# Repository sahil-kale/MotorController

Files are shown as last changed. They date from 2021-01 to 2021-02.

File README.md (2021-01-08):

# Hornet Hybrid Brushed/Brushless Motor Controller
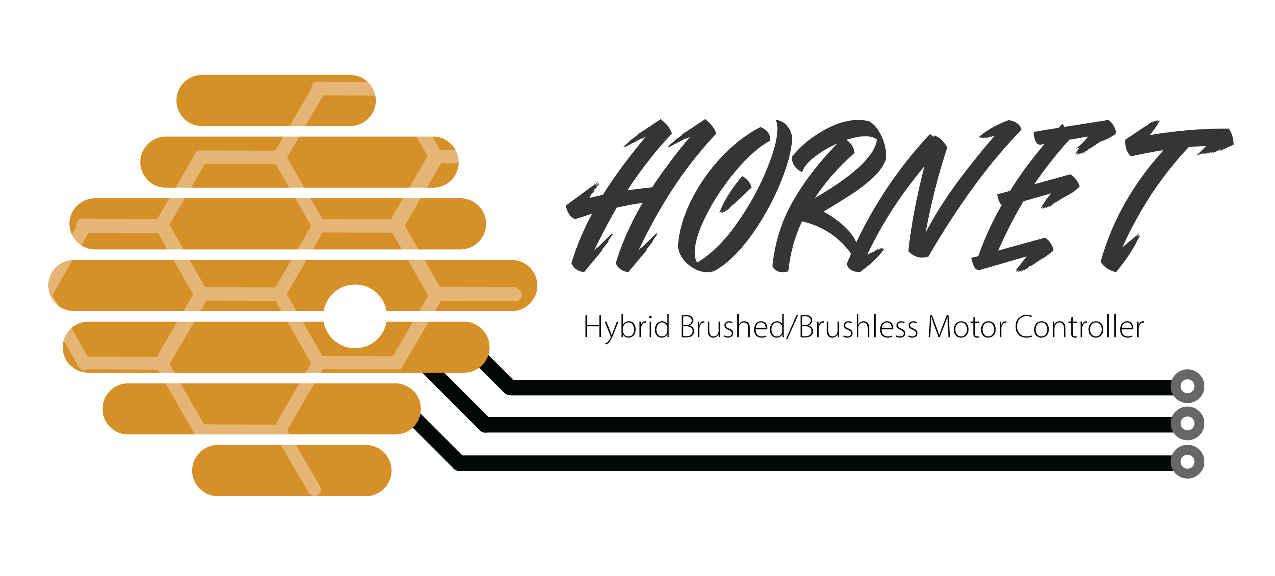
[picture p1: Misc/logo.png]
Logo Photo


## 1.1 General Summary

The HORNET MOTOR CONTROLLER is a 5A/24V hybrid brushed and brushless motor controller designed for robotic applications.

## 1.2 Feature Overview
- Servo-style PWM control interface
- Quadrature Encoder Support
- RGB Status LED
- PIDf Motion Magic
- CAN, UART, and USB data interfaces
- Brake/Coast mode

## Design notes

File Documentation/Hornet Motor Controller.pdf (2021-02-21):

# Hornet Motor Controller

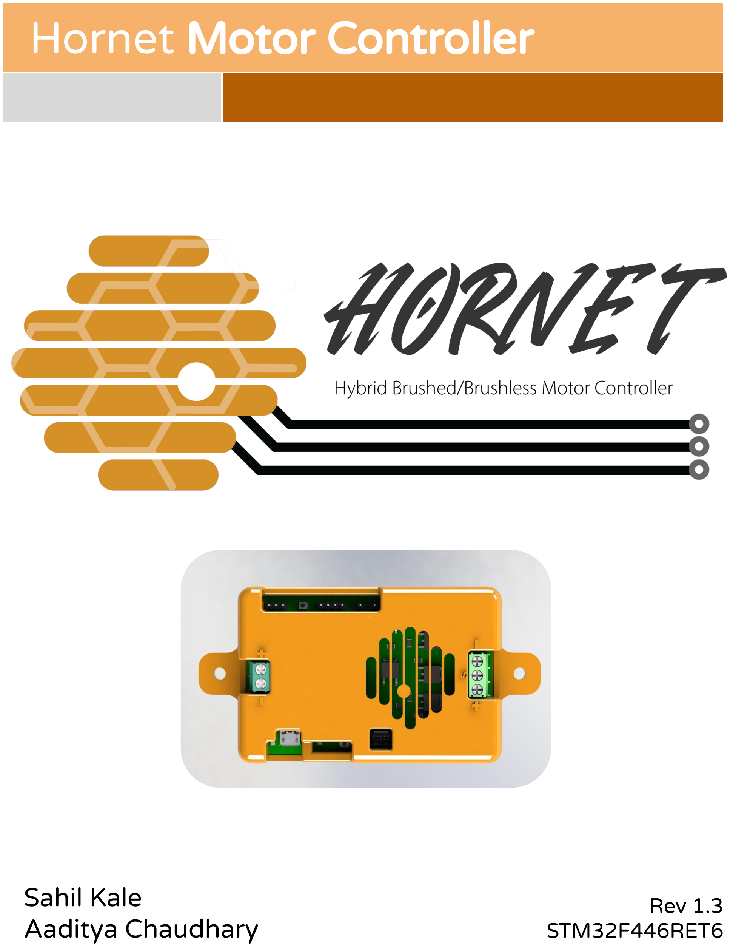
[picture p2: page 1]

## Sahil Kale Aaditya Chaudhary

Rev 1.3
STM32F446RET6

### 1.1 General Summary

The HORNET MOTOR CONTROLLER is a 5A/24V hybrid brushed and brushless motor controller designed for robotic applications based on an ARM Cortex STM32 processor

### 1.2 Feature Overview

- Servo-style PWM control interface
- Quadrature Encoder Support
- RGB Status LED
- PIDF feedback control
- Motion Profiling
- CAN, UART, and USB data interfaces
- Brake/Coast mode

## Section 1 Overview

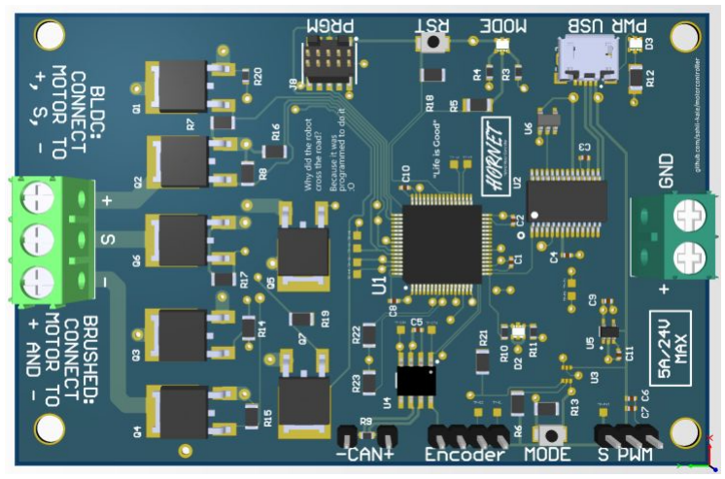
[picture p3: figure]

Figure 1.1 Board View

### 1.3 Pin Mappings

The HORNET MOTOR CONTROLLER features several communication methods . The wiring for these interfaces are located on the left side of the casing. The inputs are broken up into pin headers, in order from top to bottom.

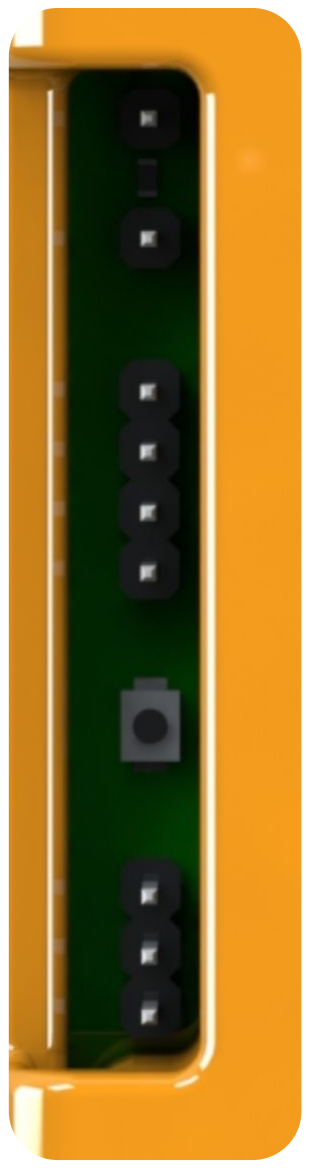
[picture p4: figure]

Controller Area Network (CAN) Wiring
- 1. CAN DIFFERENTIAL LOW
- 2. CAN DIFFERENTIAL HIGH

Quadrature Encoder Pins
- 3. GND
- 4. 5V OUT*
- 5. ENCODER IN 1
- 6. ENCODER IN 2

Servo-Style PWM
- 7. SIGNAL
- 8. 5V I/O*
- 9. GND

*Note: These pins capable of powering an external device at 5V/150 mA within the specified operating limits.

## Section 1 Overview

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
Table 2.1 General Electrical Specifications

Section 2 | Motor Control Specifications
Parameter | Min | Typ | Max | Units
Supply Voltage | 5.5 | - | 24 | V
Max Current | - | - | 5 | A
Output Frequency | - | 2 | - | MHz

Table 2.2 PWM input specifications

Parameter | Min | Typ | Max | Units
Default Full-Forward Pulse | - | 2000 | - | us
Default Neutral Pulse | 1450 | 1500 | 1550 | us
Default Full-Reverse Pulse | - | 1000 | - | us
Input Frequency | 25 | 50 | 100 | Hz
Input Voltage | 3.8 | 5 | 5.5 | V

### 2.2 Brake/Coast Mode

The HORNET MOTOR CONTROLLER features the ability to utilize the connected motor’s counter-electromotive force in order to lock the motor in place. The Brake/Coast mode is toggled in firmware with CAN or UART signals (see Section 3.3.2).

### 2.1 Motor Control Specifications

### 3.1 LED Status Codes

The HORNET MOTOR CONTROLLER features an RGB LED that is used to communicate information about the current state of the controller.

Section 3 | Interfaces
Name | Interval | Interval | Interval | Interval
Proportional Forward
Proportional Back
No Signal, Coast
Neutral Coast
Neutral Brake

Figure 3.1.1 LED Status Codes

### 3.2 CAN/UART Interface

### 3.2.1 CAN Interface Specifics

- CAN ID: 0x254
- Speed: 1Mbit/s

Note that the HORNET MOTOR CONTROLLER has an integrated 120 ohm resistor, allowing it to terminate an existing CAN network

### 3.2.2 UART Interface Specifics

- Baud Rate: 115200

## Section 3 Interfaces

### 3.3 CAN/UART Command Specification

### 3.3.1 Command Format

- Commands are made up of a leading value, to specify the command
- All values following the command specifier are parameters fed into the command

Note that the HORNET MOTOR CONTROLLER can accept a max of 7 parameters and that they must be unsigned 8 bit integers

### 3.3.2 Available Commands

Note that the parameters have been listed

- Set Speed
- Identifier: 0x00
- Parameters:
- Speed, as an unsigned integer from 0-1023, where 0 represents full speed reversed, and 1023 represents full speed forwards
- Set Brushed
- Identifier: 0x01
- Parameters:
- Set Brushed, as an unsigned integer where 0 is false and 1 is true

## Section 3 Interfaces

- Set CAN
- Identifier: 0x02
- Parameters:
- Set whether to use CAN for speed or PWM, as an unsigned 8 bit integer. Send 0 for CAN and 1 for PWM
- Set Coast/Brake
- Identifier: 0x03
- Parameters:
- Unsigned 8 bit integer. Send 0 for coast mode and 1 for brake mode
- Set Acceleration
- Identifier: 0x04
- Parameters:
- Profile number for the trapezoidal profile to modify, starting at 0
- Acceleration, as a double that must be sent as 2 unsigned 8 bit integers
- Set Velocity
- Identifier: 0x05
- Parameters:
- Profile number for the trapezoidal profile to modify, starting at 0
- Max Velocity, as a double that must be sent as 2 unsigned 8 bit integers

## Section 3 Interfaces

- Set P coefficient
- Identifier: 0x06
- Parameters:
- PIDF Profile number, starting at 0
- P coefficient as a double sent as 2 unsigned 8 bit integers
- Set I coefficient
- Identifier: 0x07
- Parameters:
- PIDF Profile number, starting at 0
- I coefficient as a double sent as 2 unsigned 8 bit integers
- Set D coefficient
- Identifier: 0x08
- Parameters:
- PIDF Profile number, starting at 0
- D coefficient as a double sent as 2 unsigned 8 bit integers
- Set F coefficient
- Identifier: 0x09
- Parameters:
- PIDF Profile number, starting at 0
- F coefficient as a double sent as 2 unsigned 8 bit integers

## Section 3 Interfaces

- Start Triangle Motion Profile
- Identifier: 0x10
- Parameters:
- Distance, in encoder ticks,as a 32 bit signed integer sent as 4 unsigned 8 bit integers
- Time, in seconds, as a double sent as 2 unsigned 8 bit integers
- Start Trapezoidal Motion Profile
- Identifier: 0x11
- Parameters:
- Trapezoidal Profile number, starting at 0 [single unsigned 8 bit integer]
- Velocity PIDF Profile to use, starting at 0 [single unsigned 8 bit integer]
- Distance in encoder ticks to travel, as a 32 bit signed integer [4 unsigned 8 bit integers]
- Start PIDF Feedback Control
- Identifier: 0x12
- Parameters:
- Input Type, 0 for encoder position and 1 for encoder velocity [unsigned 8 bit integer]
- Target of the PIDF loop, as a double [ 2 unsigned 8 bit integers]

### 4.1 Triangle Motion Profile Generator

The HORNET MOTOR CONTROLLER can generate triangular motion profiles on the fly, when given both a distance in encoder ticks to travel and the time needed to reach the target. The resulting velocity-time profile does not require a given acceleration because it calculates the acceleration based on the given time and distance. Once the profile is generated, a velocity PIDF config will need be selected to actually follow the profile.

## Section 4 Motion Profiles

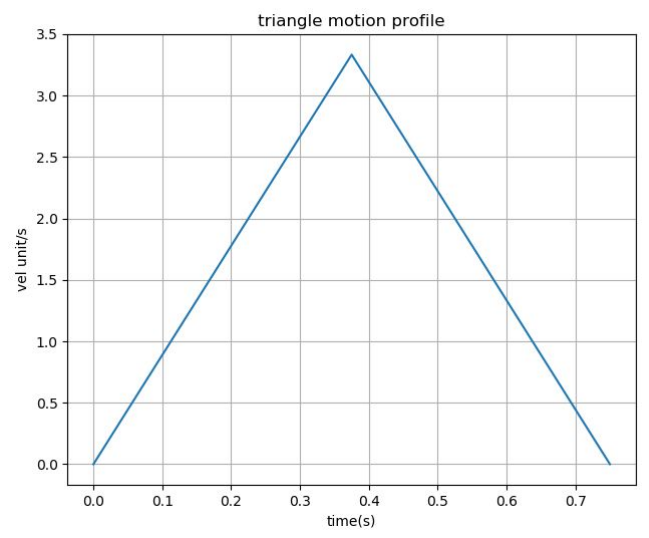
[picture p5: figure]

Figure 4.1.1 Triangle Motion Graph

### 4.2 Trapezoidal Motion Profile Generator

The HORNET MOTOR CONTROLLER can generate trapezoidal motion profiles on the fly, when given a distance in encoder ticks to travel. The controller has 8 available trapezoidal profiles. To use a profile, a max velocity and acceleration must be set for the profile. These values will be used to generate the profile. Once the profile is generated, a PIDF slot will need be selected to follow the profile. If the max velocity is not reached, but half the distance has been traveled, the profile will be a triangular profile rather than a trapezoidal one.

## Section 4 Motion Profiles

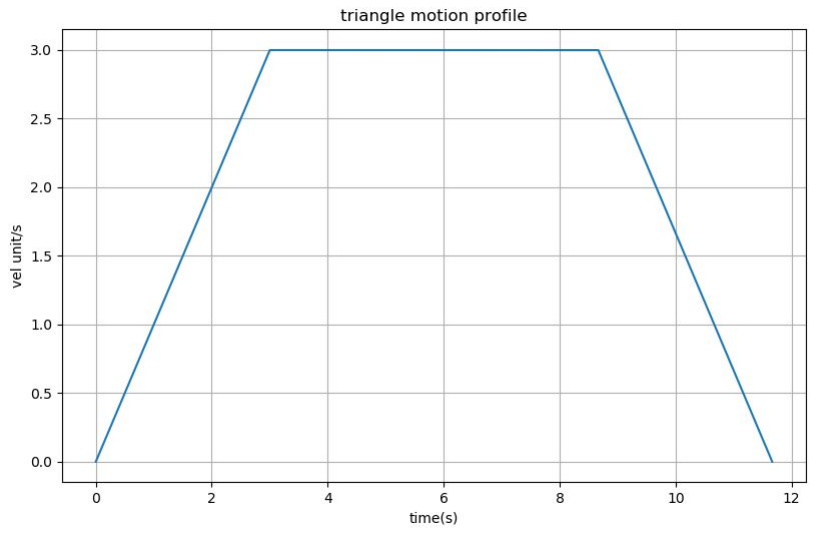
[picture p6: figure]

Figure 4.2.1 Trapezoidal Motion profile graph

## Section 4 Motion Profiles

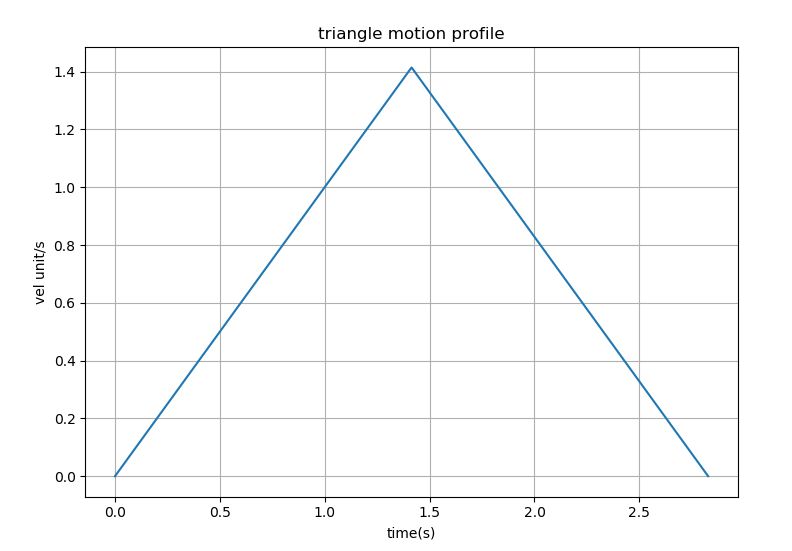
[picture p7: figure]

Figure 4.2.2 Trapezoidal motion profile graph in fallback mode

### 4.3 User Notes

- It is a good idea to test out possible displacement, velocity, and acceleration values with the graphs before using them in practice.
- For most applications, trapezoidal profiles work better and are safer than triangular profiles.
- Trapezoidal profile generator will fallback to a triangle profile if a trapezoidal one can’t be made with the given displacement.

## Appendix A Schematic

### A.1 - Schematic

The schematics for the HORNET MOTOR CONTROLLER are available at the following link:

https://github.com/sahil-kale/MotorController/blob/main/HORNET_MOTOR_CONTROLLER/HORNET_MOTOR_CONTROLLER.pdf (https://github.com/sahil-kale/MotorController/blob/main/HORNET_MOTOR_CONTROLLER/HORNET_MOTOR_CONTROLLER.pdf)

## Appendix B Case Mechanical Drawing

### A.2 - Mechanical Drawing

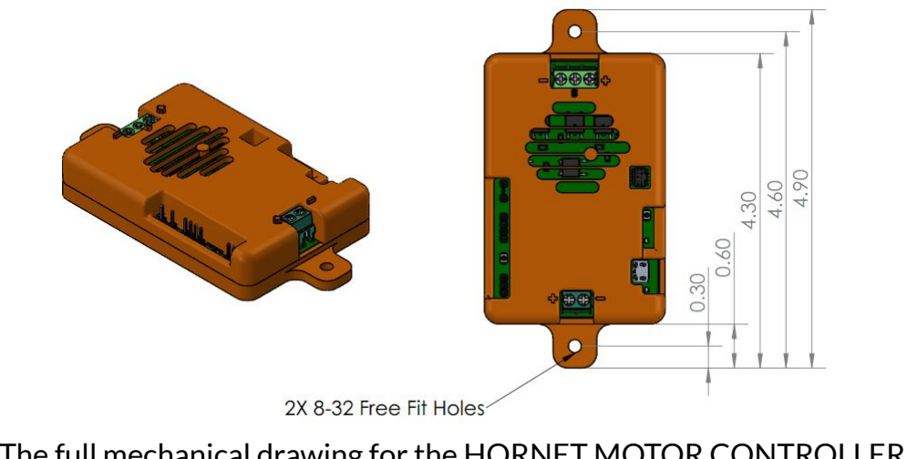
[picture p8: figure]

The full mechanical drawing for the HORNET MOTOR CONTROLLER is available at the following link:

https://github.com/sahil-kale/MotorController/blob/3d-model/3d-model/Hornet_Controller.pdf (https://github.com/sahil-kale/MotorController/blob/3d-model/3d-model/Hornet_Controller.pdf)

## Appendix C Design Decisions

### A.3 Design Decisions

A.3.1 Electrical Design Decisions
- A 4 layer PCB was chosen in order to aid with the relatively high amount of current that the board would be subjected to. Having dedicated ground and power planes ensured that power integrity was not an issue that would be faced by the HORNET MOTOR CONTROLLER.

A.3.2 Processor Decision
- An STM32F446RET6 was chosen as it was a proven microcontroller with 7 unique timer modules (3 are currently used), as well as
UART, CAN, and SPI capability. Although the requirement for SPI was removed partway through development in favour of quadrature encoder support, the capability exists for the HORNET MOTOR CONTROLLER to support SPI encoders.

A.3.3 Firmware Decisions
- As a result of the variety of managers and classes being called by interrupts, singletons were employed in order to ensure that timer modules are utilized in the intended method and that copies of the managers are not inadvertently made. Additionally, compared to static functions, singletons offered the ability to encapsulate our code, increasing its reliability and maintainability.

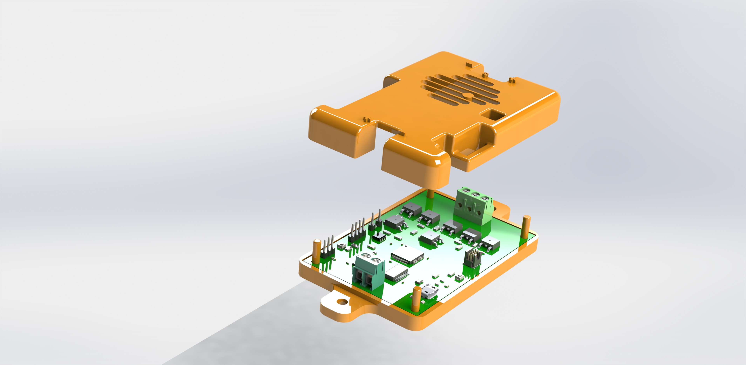
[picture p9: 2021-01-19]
3d-model/OpenCase.JPG

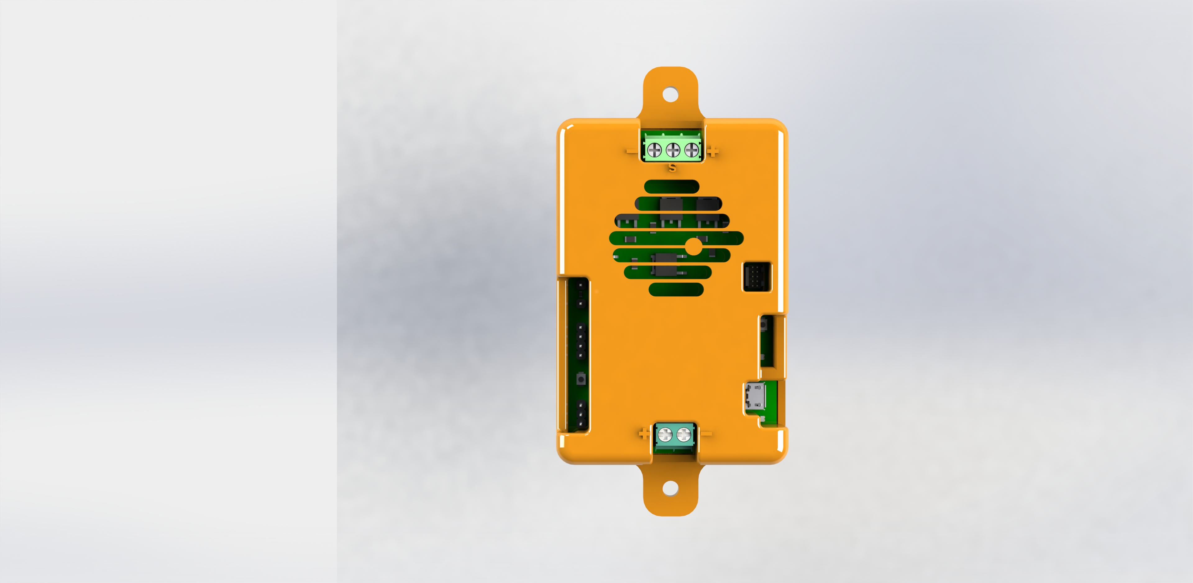
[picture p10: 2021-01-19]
3d-model/TopView.JPG

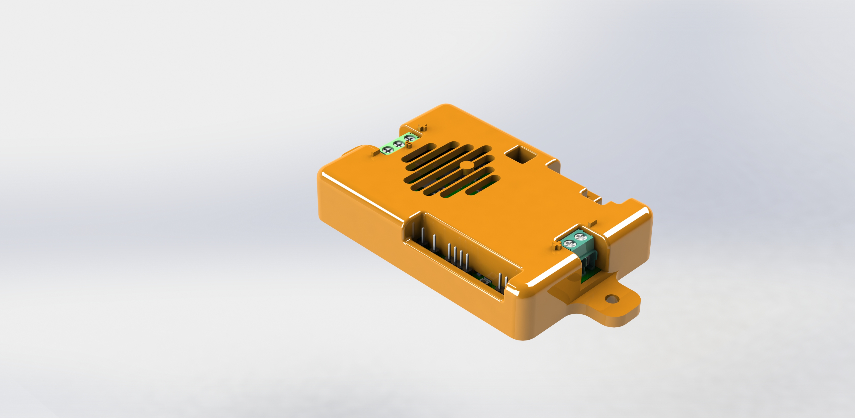
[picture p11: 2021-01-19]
3d-model/AngledView.JPG

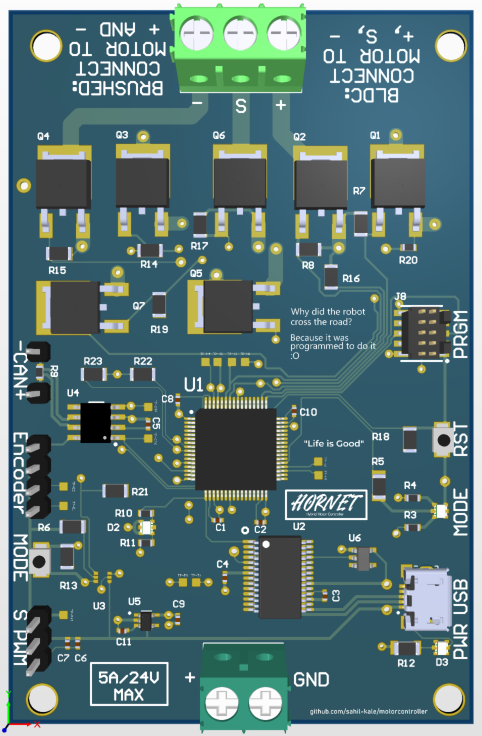
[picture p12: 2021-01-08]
Misc/boardrender.png

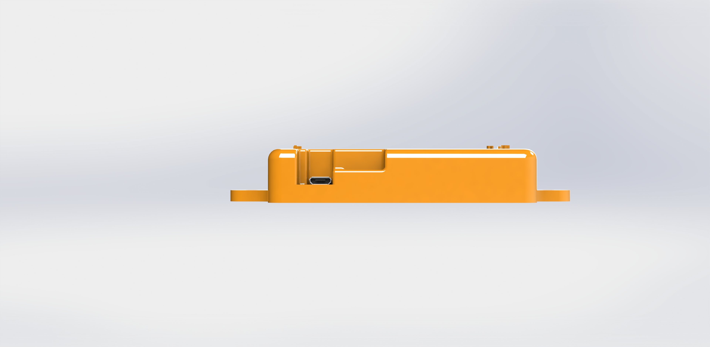
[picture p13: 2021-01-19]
3d-model/LeftView.JPG

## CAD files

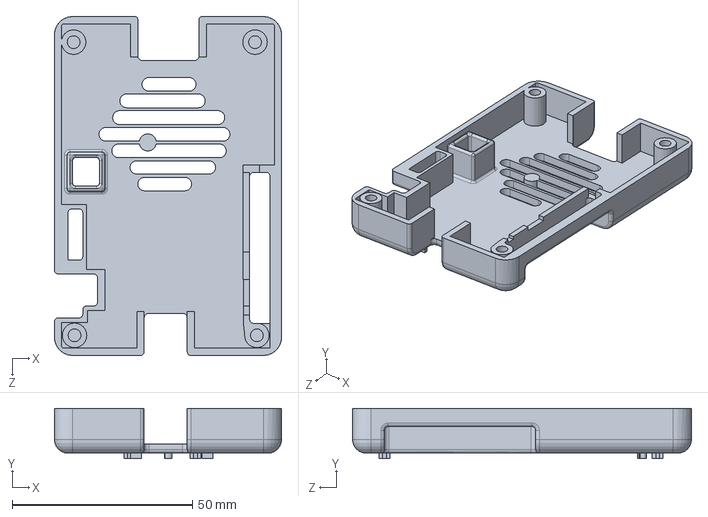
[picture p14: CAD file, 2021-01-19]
3d-model/case_top.SLDPRT
63.0 x 14.0 x 94.0 mm

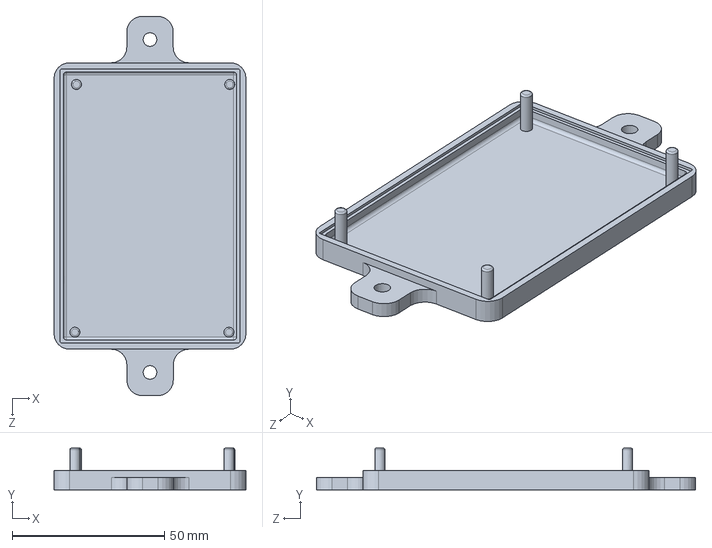
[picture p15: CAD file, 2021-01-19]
3d-model/case_bottom.SLDPRT
63.0 x 13.7 x 124.5 mm

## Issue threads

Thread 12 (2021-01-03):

Mode button toggle & state machine

sahil-kale, 2021-01-03:
There is a mode button on the board. Currently, 2 states are active:
1) Disabled - no output shall be called
2) Enabled

sahil-kale, 2021-01-04:
State machine addon:
3. Motion Magic Mode

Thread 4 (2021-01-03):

PWM input

sahil-kale, 2021-01-03:
PWM input with a servo-style command (50Hz with 5-10% duty cycle) will be used to control the motor.

Closed 2021-01-05.

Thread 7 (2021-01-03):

Encoder Input

sahil-kale, 2021-01-03:
A standard quadrature encoder is supported by this motor controller. GPIO interrupts can be used to make the facilitate of this easier. Once this is done, the inputs can be linked to the outputs via the motion profile functions

Closed 2021-01-08.

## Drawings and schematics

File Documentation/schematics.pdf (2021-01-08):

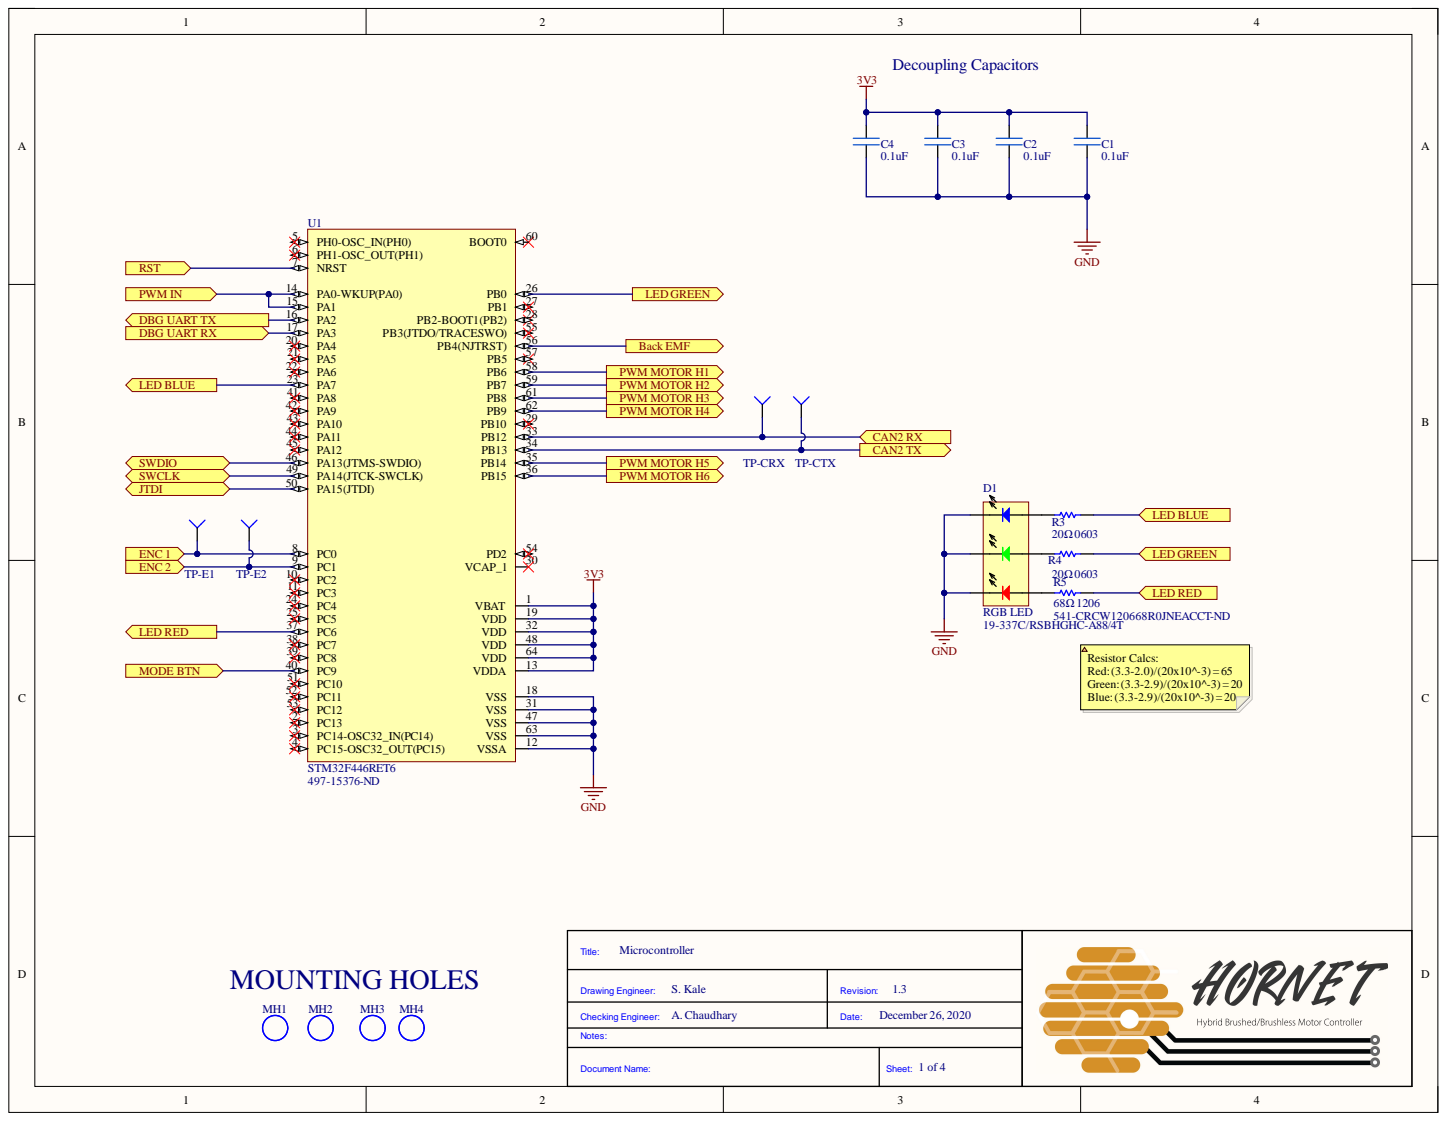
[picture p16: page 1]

TP-CRX TP-CTX

Title: Microcontroller

Drawing Engineer: S. Kale | Revision: 1.3

Checking Engineer: A. Chaudhary | Date: December 26, 2020

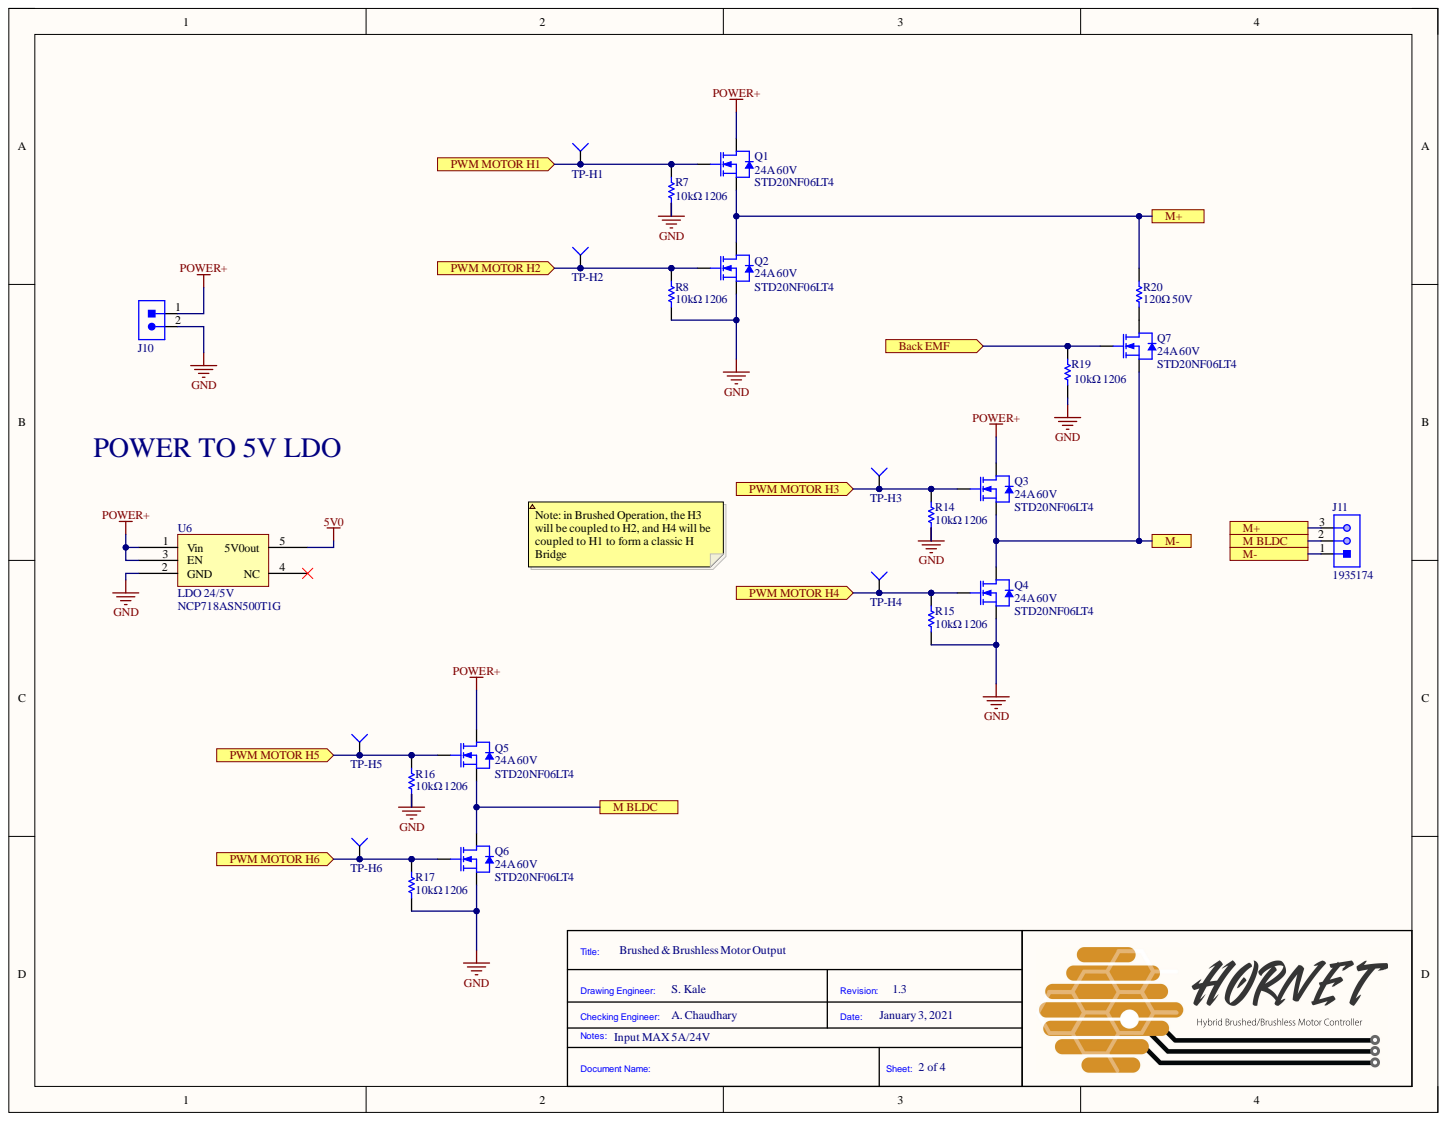
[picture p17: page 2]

Note: in Brushed Operation, the H3
will be coupled to H2, and H4 will be
coupled to H1 to form a classic H
Bridge

Title: Brushed & BrushlessMotor Output

Drawing Engineer: S. Kale | Revision: 1.3

Checking Engineer: A. Chaudhary | Date: January 3, 2021

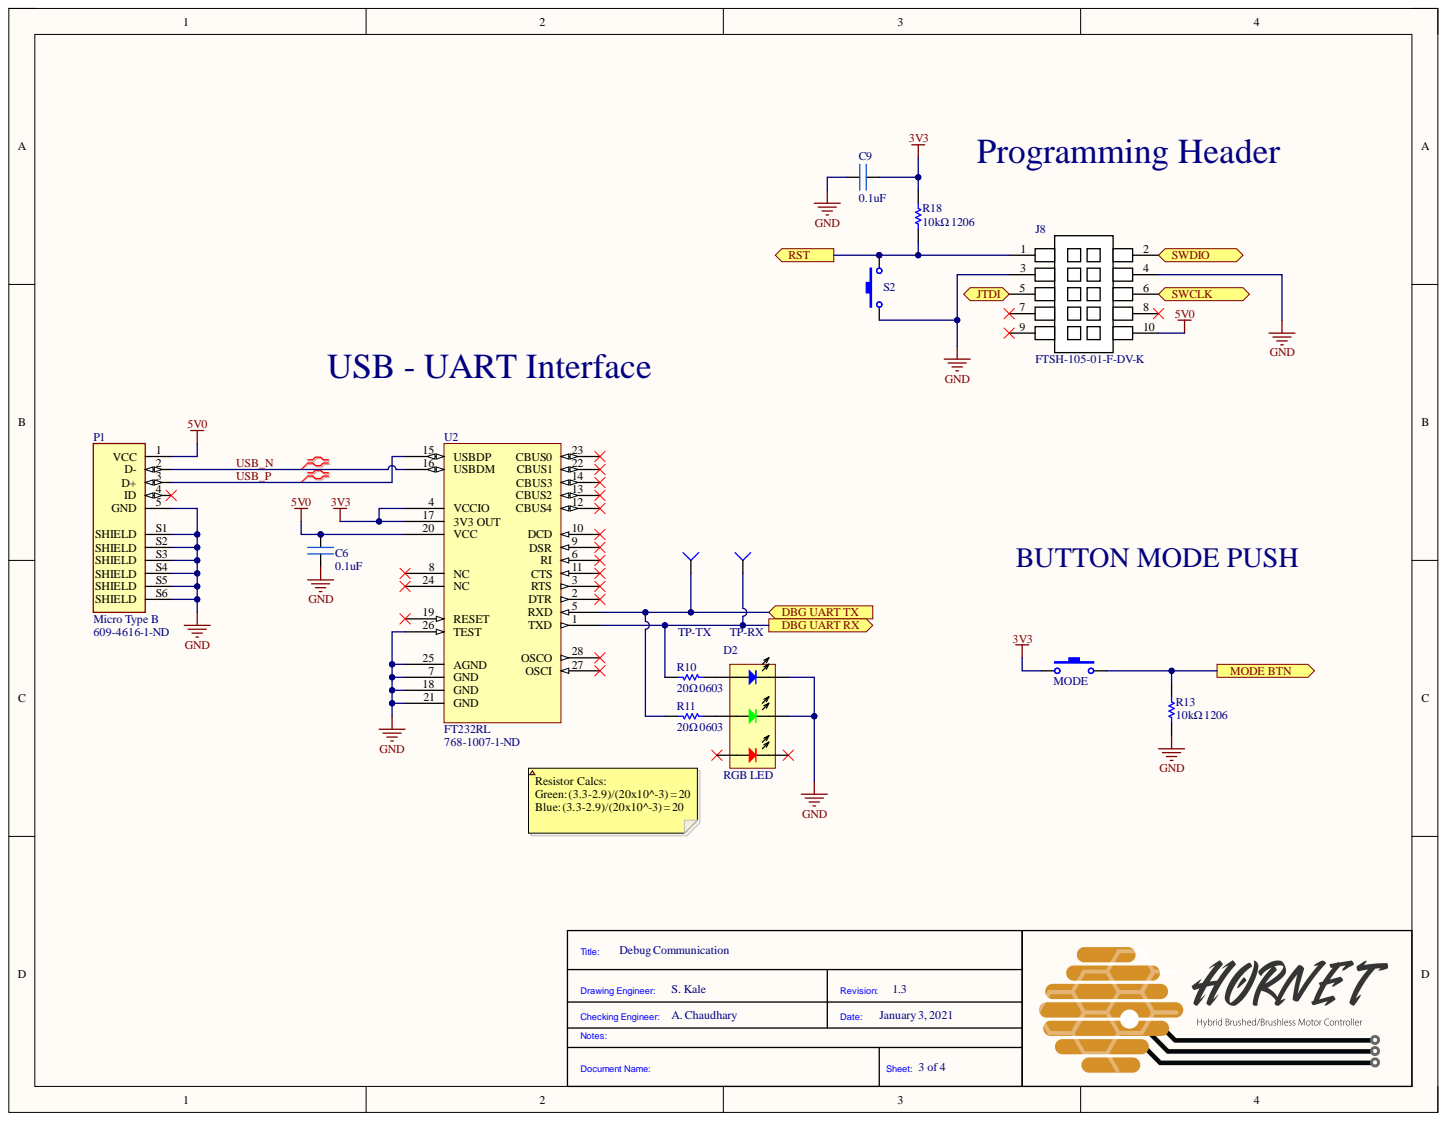
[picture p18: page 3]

AGND 25
GND 7
GND 18
GND 21

Title: DebugCommunication

Drawing Engineer: S. Kale | Revision: 1.3

Checking Engineer: A. Chaudhary | Date: January 3, 2021

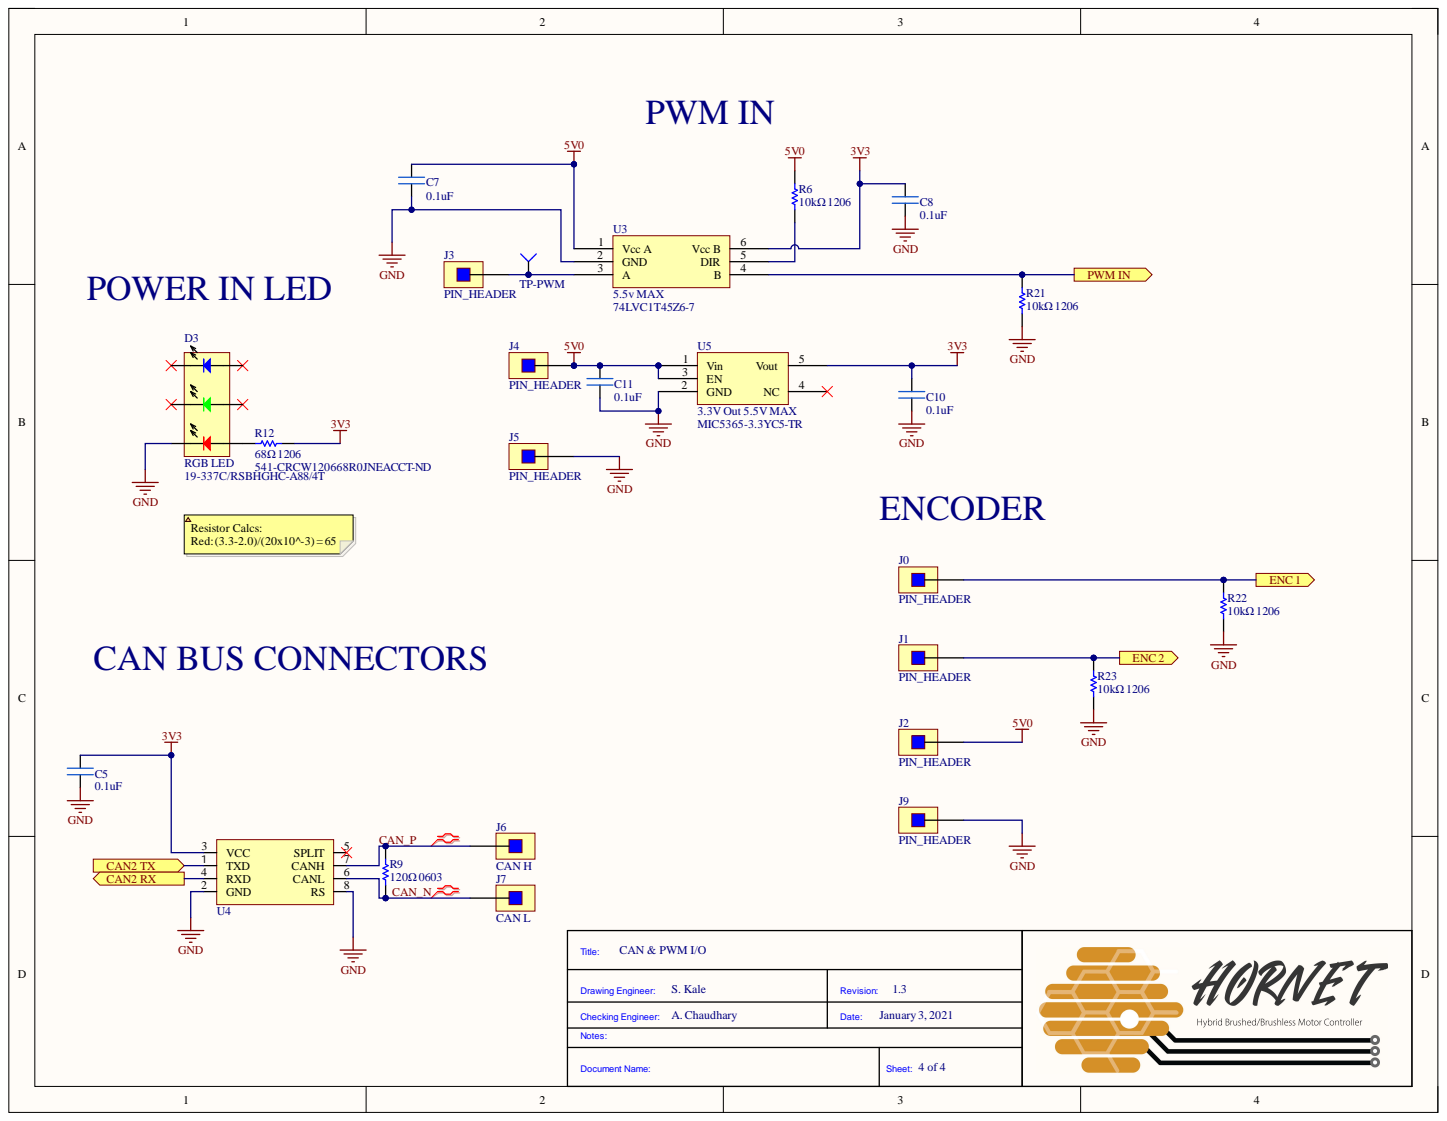
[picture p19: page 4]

Title: CAN & PWM I/O

Drawing Engineer: S. Kale | Revision: 1.3

Checking Engineer: A. Chaudhary | Date: January 3, 2021

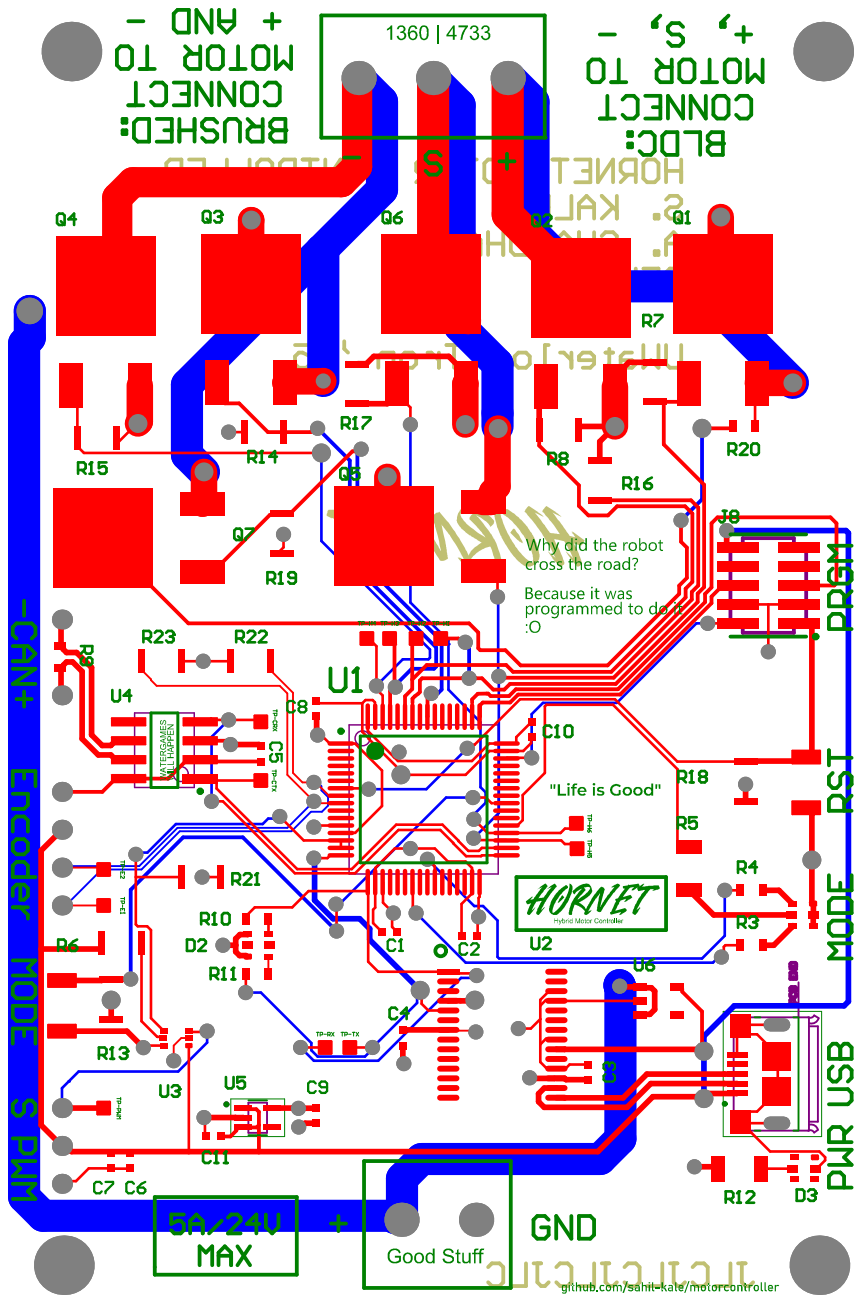
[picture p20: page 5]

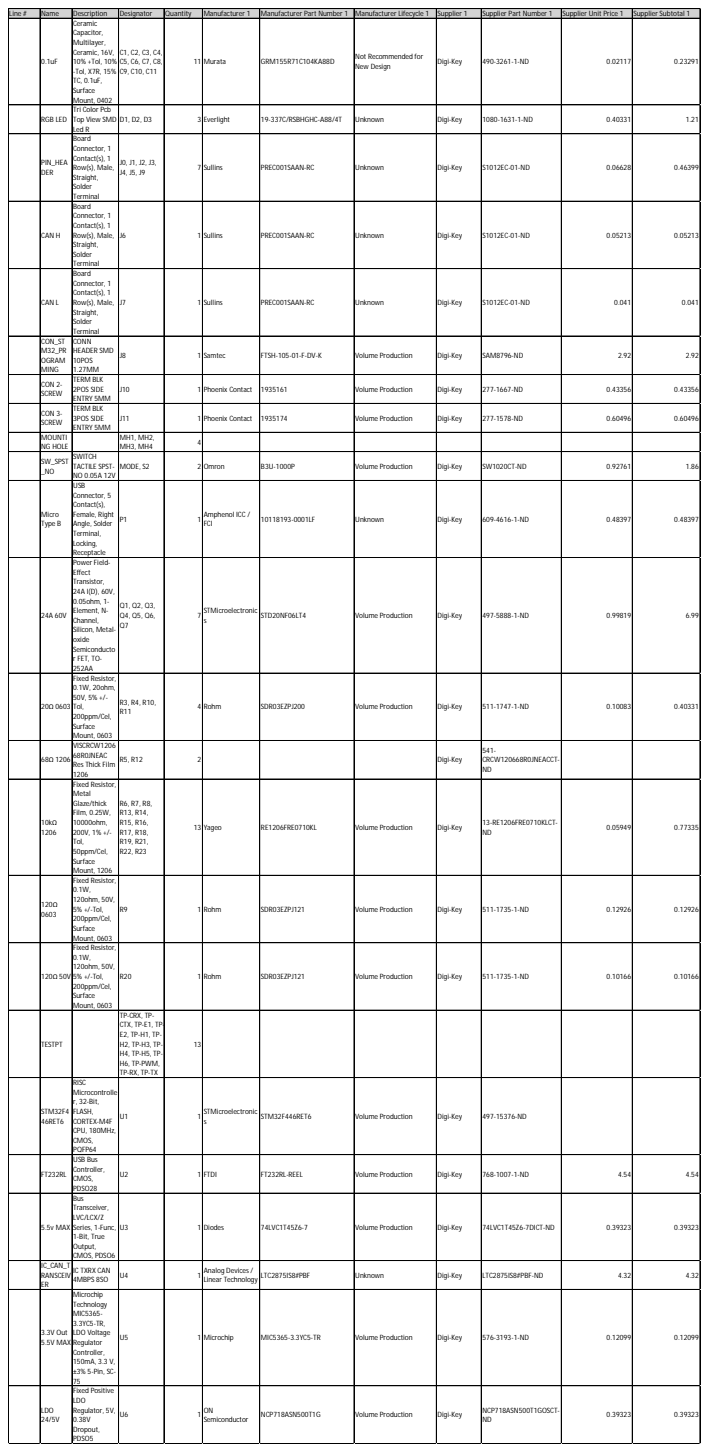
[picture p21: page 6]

0.1uF | Ceramic Capacitor, Multilayer, Ceramic, 16V, 10% +Tol, 10% -Tol, X7R, 15% TC, 0.1uF, Surface Mount, 0402 | C1, C2, C3, C4, C5, C6, C7, C8, C9, C10, C11 | 11 | Murata | GRM155R71C104KA88D | Not Recommended for New Design | Digi-Key | 490-3261-1-ND | 0.02117 | 0.23291

RGB LED | Tri Color Pcb Top View SMD Led R | D1, D2, D3 | 3 Everlight | | 19-337C/RSBHGHC-A88/4T | Unknown | Digi-Key | 1080-1631-1-ND | 0.40331 | 1.21

PIN_HEA DER | Board Connector, 1 Contact(s), 1 Row(s), Male, Straight, Solder Terminal | J0, J1, J2, J3, J4, J5, J9 | 7 | Sullins | PREC001SAAN-RC | Unknown | Digi-Key | S1012EC-01-ND | 0.06628 | 0.46399

CAN H | Board Connector, 1 Contact(s), 1 Row(s), Male, Straight, Solder Terminal | J6 | 1 | Sullins | PREC001SAAN-RC | Unknown | Digi-Key | S1012EC-01-ND | 0.05213 | 0.05213

CAN L | Board Connector, 1 Contact(s), 1 Row(s), Male, Straight, Solder Terminal | J7 | 1 | Sullins | PREC001SAAN-RC | Unknown | Digi-Key | S1012EC-01-ND | 0.041 | 0.041

CON_ST M32_PR OGRAM MING | CONN HEADER SMD 10POS 1.27MM | J8 | 1 | Samtec | FTSH-105-01-F-DV-K | Volume Production | Digi-Key | SAM8796-ND | 2.92 | 2.92

CON 2-SCREW | TERM BLK 2POS SIDE ENTRY 5MM | J10 | 1 | Phoenix Contact | 1935161 | Volume Production | Digi-Key | 277-1667-ND | 0.43356 | 0.43356

CON 3-SCREW | TERM BLK 3POS SIDE ENTRY 5MM | J11 | 1 | Phoenix Contact | 1935174 | Volume Production | Digi-Key | 277-1578-ND | 0.60496 | 0.60496

MOUNTI NG HOLE | | MH1, MH2, MH3, MH4 | 4

SW_SPST _NO | SWITCH TACTILE SPST-NO 0.05A 12V | MODE, S2 | 2 Omron | | B3U-1000P | Volume Production | Digi-Key | SW1020CT-ND | 0.92761 | 1.86

Micro Type B | USB Connector, 5 Contact(s), Female, Right Angle, Solder Terminal, Locking, Receptacle | P1 | 1 | Amphenol ICC / FCI | 10118193-0001LF | Unknown | Digi-Key | 609-4616-1-ND | 0.48397 | 0.48397

24A 60V | Power Field-Effect Transistor, 24A I(D), 60V, 0.05ohm, 1-Element, N-Channel, Silicon, Metal-oxide Semiconducto r FET, TO-252AA | Q1, Q2, Q3, Q4, Q5, Q6, Q7 | 7 | STMicroelectronic s | STD20NF06LT4 | Volume Production | Digi-Key | 497-5888-1-ND | 0.99819 | 6.99

20Ω 0603 | Fixed Resistor, 0.1W, 20ohm, 50V, 5% +/-Tol, 200ppm/Cel, Surface Mount, 0603 | R3, R4, R10, R11 | 4 Rohm | | SDR03EZPJ200 | Volume Production | Digi-Key | 511-1747-1-ND | 0.10083 | 0.40331

68Ω 1206 | VISCRCW1206 68R0JNEAC Res Thick Film 1206 | R5, R12 | 2 | | | | Digi-Key | 541-CRCW120668R0JNEACCT-ND

10kΩ 1206 | Fixed Resistor, Metal Glaze/thick Film, 0.25W, 10000ohm, 200V, 1% +/-Tol, 50ppm/Cel, Surface Mount, 1206 | R6, R7, R8, R13, R14, R15, R16, R17, R18, R19, R21, R22, R23 | 13 Yageo | | RE1206FRE0710KL | Volume Production | Digi-Key | 13-RE1206FRE0710KLCT-ND | 0.05949 | 0.77335

120Ω 0603 | Fixed Resistor, 0.1W, 120ohm, 50V, 5% +/-Tol, 200ppm/Cel, Surface Mount, 0603 | R9 | 1 | Rohm | SDR03EZPJ121 | Volume Production | Digi-Key | 511-1735-1-ND | 0.12926 | 0.12926

120Ω 50V | Fixed Resistor, 0.1W, 120ohm, 50V, 5% +/-Tol, 200ppm/Cel, Surface Mount, 0603 | R20 | 1 | Rohm | SDR03EZPJ121 | Volume Production | Digi-Key | 511-1735-1-ND | 0.10166 | 0.10166

TESTPT | | TP-CRX, TP-CTX, TP-E1, TP-E2, TP-H1, TP-H2, TP-H3, TP-H4, TP-H5, TP-H6, TP-PWM, TP-RX, TP-TX | 13

STM32F4 46RET6 | RISC Microcontrolle r, 32-Bit, FLASH, CORTEX-M4F CPU, 180MHz, CMOS, PQFP64 | U1 | 1 | STMicroelectronic s | STM32F446RET6 | Volume Production | Digi-Key | 497-15376-ND

FT232RL | USB Bus Controller, CMOS, PDSO28 | U2 | 1 | FTDI | FT232RL-REEL | Volume Production | Digi-Key | 768-1007-1-ND | 4.54 | 4.54
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

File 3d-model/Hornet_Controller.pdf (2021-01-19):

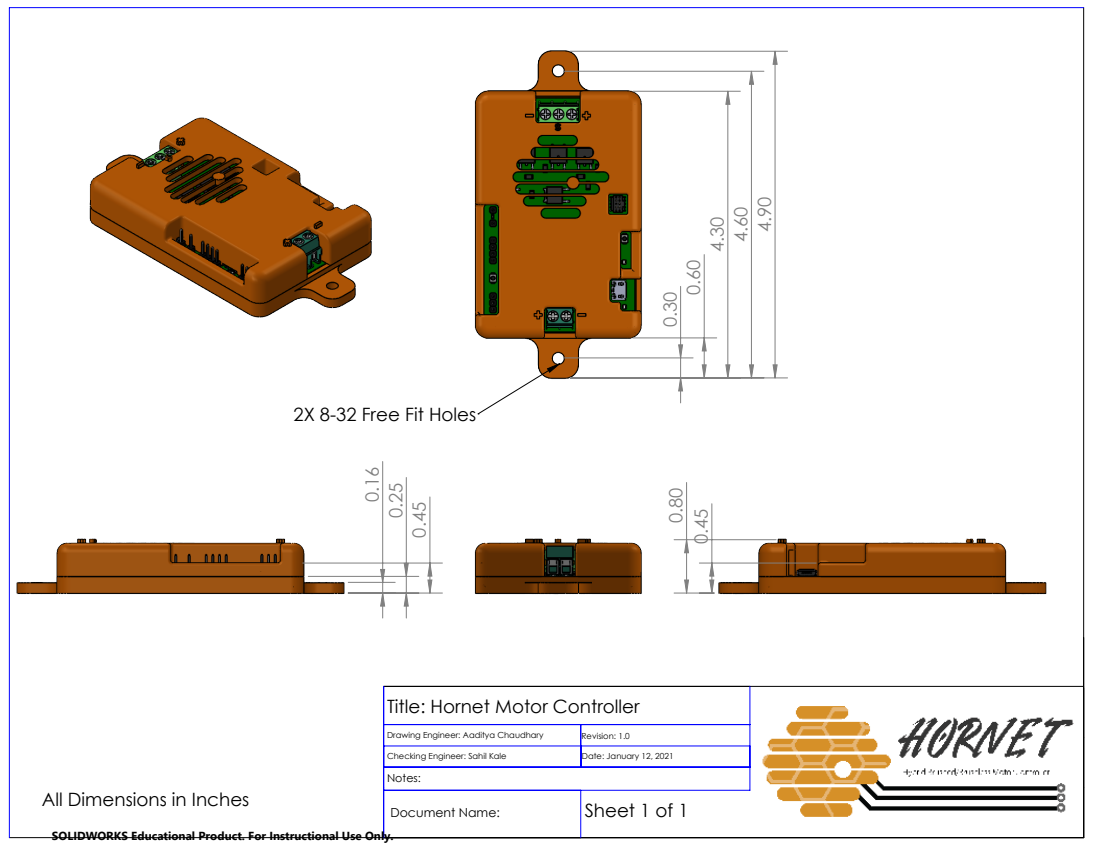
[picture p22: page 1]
Document Name:; Sheet 1 of 1

2X 8-32 Free Fit Holes 0.45 0.16 0.25

Title: Hornet Motor Controller

Drawing Engineer: Aaditya Chaudhary | Revision: 1.0

Checking Engineer: Sahil Kale | Date: January 12, 2021

All Dimensions in Inches

SOLIDWORKS Educational Product. For Instructional Use Only.

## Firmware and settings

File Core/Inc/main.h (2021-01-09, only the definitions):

#define ENC_1_Pin GPIO_PIN_0
#define ENC_1_GPIO_Port GPIOC
#define ENC_1_EXTI_IRQn EXTI0_IRQn
#define ENC_2_Pin GPIO_PIN_1
#define ENC_2_GPIO_Port GPIOC
#define ENC_2_EXTI_IRQn EXTI1_IRQn
#define LED_RED_Pin GPIO_PIN_6
#define LED_RED_GPIO_Port GPIOA
#define LED_GREEN_Pin GPIO_PIN_0
#define LED_GREEN_GPIO_Port GPIOB
#define MOTOR_H5_Pin GPIO_PIN_14
#define MOTOR_H5_GPIO_Port GPIOB
#define MOTOR_H6_Pin GPIO_PIN_15
#define MOTOR_H6_GPIO_Port GPIOB
#define LED_BLUE_Pin GPIO_PIN_7
#define LED_BLUE_GPIO_Port GPIOC
#define MODE_BTN_Pin GPIO_PIN_9
#define MODE_BTN_GPIO_Port GPIOC
#define BackEMF_Pin GPIO_PIN_4
#define BackEMF_GPIO_Port GPIOB
#define MOTOR_H1_Pin GPIO_PIN_6
#define MOTOR_H1_GPIO_Port GPIOB
#define MOTOR_H2_Pin GPIO_PIN_7
#define MOTOR_H2_GPIO_Port GPIOB
#define MOTOR_H3_Pin GPIO_PIN_8
#define MOTOR_H3_GPIO_Port GPIOB
#define MOTOR_H4_Pin GPIO_PIN_9
#define MOTOR_H4_GPIO_Port GPIOB

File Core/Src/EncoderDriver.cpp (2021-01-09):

import "EncoderDriver.hpp"


//encoder driver constructor
EncoderDriver::EncoderDriver() {
	velocity = 0;
	position = 0;
	lastInterruptTime = 0;
}

EncoderDriver* EncoderDriver::instance = nullptr;

//gets the single instance, creates one if it doesnt exist 
EncoderDriver* EncoderDriver::getInstance() {
	if(!instance) {
		instance = new EncoderDriver();
	}
	
	return instance;
}

//getters and setters
int32_t EncoderDriver::getPosition() {
	return position;
}

void EncoderDriver::setPosition(int32_t pos) {
	position = pos;
}

double EncoderDriver::getVelocity() {
	return velocity;
}


//two functions to be called by the gpio interrupt
void EncoderDriver::intChannelA(bool rising) {
	//get the value of each channel
	bool chanA = rising;
	bool chanB = HAL_GPIO_ReadPin(GPIOC, GPIO_PIN_1);
	
	//compare channels to determine direction of system	
	bool forward = chanA != chanB;

	uint32_t time = HAL_GetTick();	
	//get the time since the last interrrupt
	uint32_t dt  = time - lastInterruptTime;	
	

	//modify position and velocity
	if(forward) {
		position += 1;	
		velocity = 1/dt;
	} else {
		position -= 1;	
		velocity = -1/dt;
	}

	lastInterruptTime = time; 
}

void EncoderDriver::intChannelB(bool rising) {
	//get the value of each channel
	bool chanA = HAL_GPIO_ReadPin(GPIOC, GPIO_PIN_0);
	bool chanB = rising;

	//compare channels to determine direction of system	
	bool forward = chanA == chanB;	
	uint32_t time = HAL_GetTick();
	//get the time since the last interrrupt
	uint32_t dt  = time - lastInterruptTime;	
	//modify position and velocity
	if(forward) {
		position += 1;	
		velocity = 1/dt;
	} else {
		position -= 1;	
		velocity = -1/dt;
	}
	lastInterruptTime = time; 
}

//callback to be called on gpio interrupt
void HAL_GPIO_EXTI_Callback(uint16_t GPIO_Pin) {
	
	if (GPIO_Pin == 0) { //enc 1 pin - channel a
		EncoderDriver.getInstance().intChannelA(HAL_GPIO_ReadPin(GPIOC, GPIO_PIN_0));
	} else if(*GPIO_Pin == 1) { //enc 2 pin - channel b
		EncoderDriver.getInstance().intChannelB(HAL_GPIO_ReadPin(GPIOC, GPIO_PIN_1));
	}
}

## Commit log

2020-12-20 Create Makefiles
    [KALE_MOTOR_CONTROLLER.SCHLIB, STM32.SchDoc]
2020-12-25 Add in pin changes
    [KALE_MOTOR_CONTROLLER.SCHLIB]
2020-12-25 Change Names
    [HORNET_MOTOR_CONTROLLER.PcbLib, HORNET_MOTOR_CONTROLLER.PrjPcb, HORNET_MOTOR_CONTROLLER.SCHLIB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]
2020-12-25 Add in pin markers
    [AVRTank.PcbLib, AVRTank.SchLib, HORNET_MOTOR_CONTROLLER.PcbLib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]
2020-12-25 Change Name
    [AVRTank.PcbLib, AVRTank.SchLib, HORNET_MOTOR_CONTROLLER.PcbLib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]
2020-12-25 Add in H bridge docs
    [HBridge.SchDoc, HORNET_MOTOR_CONTROLLER.PcbLib, HORNET_MOTOR_CONTROLLER.SCHLIB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]
2020-12-26 Add in voltage dividers and LED's
    [HBridge.SchDoc, HORNET_MOTOR_CONTROLLER.PcbLib, HORNET_MOTOR_CONTROLLER.PrjPcb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]
2020-12-26 Add in generated PDF
    [STM32.SchDoc]
2020-12-26 Add in H Bridge
    [HBridge.SchDoc, HORNET_MOTOR_CONTROLLER.PrjPcb, HORNET_MOTOR_CONTROLLER.SCHLIB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]
2020-12-26 Add in pull down resistors and title block
    [SH1 - STM32.SchDoc, SH2 - HBridge.SchDoc, SH3 - External Communication.SchDoc]
2020-12-28 Add in CAN transceivers
    [HORNET_MOTOR_CONTROLLER.PcbLib, HORNET_MOTOR_CONTROLLER.PrjPcb, HORNET_MOTOR_CONTROLLER.SCHLIB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]
2020-12-29 Seperate CAN and PWM onto different pages
    [HORNET_MOTOR_CONTROLLER.SCHLIB, SH1 - STM32.SchDoc, SH3 - Debug CommunicationSchDoc.SchDoc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]
2020-12-29 Add in debug headers
    [HORNET_MOTOR_CONTROLLER.PcbLib, HORNET_MOTOR_CONTROLLER.PrjPcb, HORNET_MOTOR_CONTROLLER.SCHLIB]
2020-12-29 Finished Brushed Schematics
    [HORNET_MOTOR_CONTROLLER.PcbLib, HORNET_MOTOR_CONTROLLER.SCHLIB, SH1 - STM32.SchDoc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]
2020-12-29 Modified smartPDF
    [HORNET_MOTOR_CONTROLLER.PrjPcb]
2020-12-30 Finish Prelim Documents
    [HORNET_MOTOR_CONTROLLER.PrjPcb, SH1 - STM32.SchDoc, SH2 - HBridge.SchDoc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]
2020-12-30 Add in backEMF
    [HORNET_MOTOR_CONTROLLER.PcbLib, HORNET_MOTOR_CONTROLLER.PrjPcb, HORNET_MOTOR_CONTROLLER.SCHLIB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]
2020-12-31 Add in PCB Document and start routing
    [HORNET_MOTOR_CONTROLLER.PcbLib, HORNET_MOTOR_CONTROLLER.PrjPcb, HORNET_MOTOR_CONTROLLER.SCHLIB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]
2021-01-01 Finish REV1
    [HORNET_MOTOR_CONTROLLER.PrjPcb, HornetPCB.PcbDoc, SH1 - STM32.SchDoc]
2021-01-02 Finish putting graphical addons
    [HornetPCB.PcbDoc]
2021-01-02 Edit board shape
    [HornetPCB.PcbDoc]
2021-01-02 Add in custom rules
    [HornetPCB.PcbDoc, SH3 - Debug Communication.SchDoc]
2021-01-02 Modify USB footprint
    [HORNET_MOTOR_CONTROLLER.PcbLib, HORNET_MOTOR_CONTROLLER.PrjPcb, HornetPCB.PcbDoc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]
2021-01-02 Remove irrelevant files
    [SH3 - Debug Communication.SchDoc]
2021-01-03 Add in LDO
    [HORNET_MOTOR_CONTROLLER.PcbLib, HORNET_MOTOR_CONTROLLER.PrjPcb, HORNET_MOTOR_CONTROLLER.SCHLIB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]
2021-01-03 Add new gitignore
    [HornetPCB.PcbDoc]
2021-01-03 switched type to makefile
2021-01-03 Update Board
    [HORNET_MOTOR_CONTROLLER.PcbLib, HORNET_MOTOR_CONTROLLER.SCHLIB, HornetPCB.PcbDoc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]
2021-01-03 Add logo to PDF
    [HORNET_MOTOR_CONTROLLER.SCHLIB, HornetPCB.PcbDoc, SH1 - STM32.SchDoc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]
2021-01-04 PCB Changes
    [HORNET_MOTOR_CONTROLLER.PrjPcb, SH4 - PWM + CAN.SchDoc]
2021-01-04 Add in PWM and remove build files
2021-01-04 Add in PWM input HPP
2021-01-04 Final PWMInput Touches
2021-01-04 Add in new LDO
    [HORNET_MOTOR_CONTROLLER.PcbLib, HORNET_MOTOR_CONTROLLER.SCHLIB, SH2 - HBridge.SchDoc]
2021-01-04 Update PCB
    [HORNET_MOTOR_CONTROLLER.PrjPcb, SH1 - STM32.SchDoc, SH4 - PWM + CAN.SchDoc]
2021-01-04 Comment PWM functions
2021-01-05 Commit LED, PWMinput, BrushedOutput (#22)
    * Commit LED, PWMinput, BrushedOutput
    * Add in isOvertime functions
    * Update led.cpp
    * Update led.cpp
2021-01-07 Update PDF
    [HORNET_MOTOR_CONTROLLER.PrjPcb]
2021-01-07 Add in UART/CAN manager
2021-01-07 Update Altium Files
    [HORNET_MOTOR_CONTROLLER.SCHLIB, SH1 - STM32.SchDoc, SH2 - HBridge.SchDoc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]
2021-01-07 Generate STEP files
    [SH1 - STM32.SchDoc, SH2 - HBridge.SchDoc, SH4 - PWM + CAN.SchDoc]
2021-01-07 Finalize BOM
    [HORNET_MOTOR_CONTROLLER.PrjPcb, HORNET_MOTOR_CONTROLLER.SCHLIB, SH1 - STM32.SchDoc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]
2021-01-08 Update PrjPcb
    [HORNET_MOTOR_CONTROLLER.PrjPcb]
2021-01-08 Add in board render
2021-01-09 Encoder driver (#27)
    * encoder driver written
    - encoder driver hpp and cpp files made
    - encoder interrupt written
    - logic written
    - not fully documented yet
    * added comments
    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
2021-01-17 Minor PCB changes
    [HORNET_MOTOR_CONTROLLER.PcbLib, HORNET_MOTOR_CONTROLLER.PrjPcb, HORNET_MOTOR_CONTROLLER.SCHLIB]
2021-01-18 Add in Brake Coast Manager (#24)
2021-01-19 Add in 3D Models (#28)
    * case_v1 and images
    * some files didn't save, so Im uploading them now
    * added part drawing
    * fixing drawing issues and creating pdf
    [case_bottom.SLDPRT, case_top.SLDPRT]
2021-02-21 Create Hornet Motor Controller.pdf

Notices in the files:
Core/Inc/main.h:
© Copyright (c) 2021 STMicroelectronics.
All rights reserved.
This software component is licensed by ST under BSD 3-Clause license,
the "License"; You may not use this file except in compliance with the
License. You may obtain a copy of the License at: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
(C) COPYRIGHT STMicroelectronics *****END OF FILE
